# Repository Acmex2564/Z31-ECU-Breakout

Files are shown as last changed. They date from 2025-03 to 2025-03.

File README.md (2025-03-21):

#Z31-ECU-Breakout

This repository contains KiCad files for a breakout board usable for the 1980s Nissan ECCS with the 36(20+16)+15 pin harness.

I used this to run an M30 ECU without chopping up my existing harness prior to fabricating a new 76-pin harness.

You will need a the 36-pin Dual-Line Interlock (DLI) header (AMP P/N 172023-1) and yet unidentified 15-pin header (looks kinda like a JPT/MCP part, marked for Mitsubishi Electric (SJB) but not in any English catalogs), and fasteners for both. The 15-pin header will need to be desoldered from a scrapped ECU; the 36-pin is available from Digikey/Mouser/etc. as of 2025.

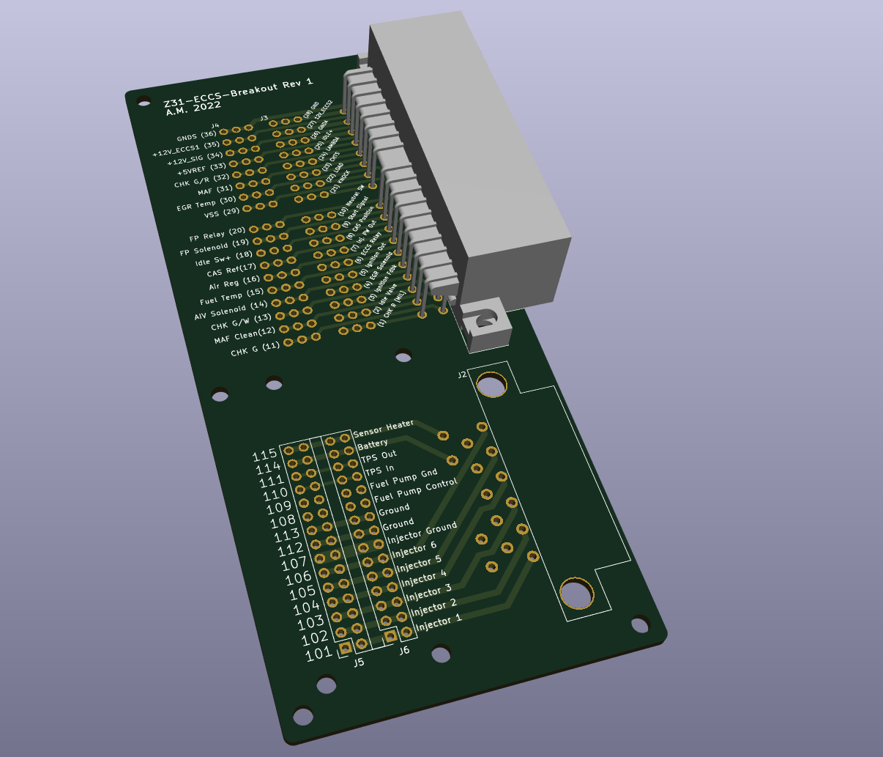
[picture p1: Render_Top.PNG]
KiCad Render of top of board


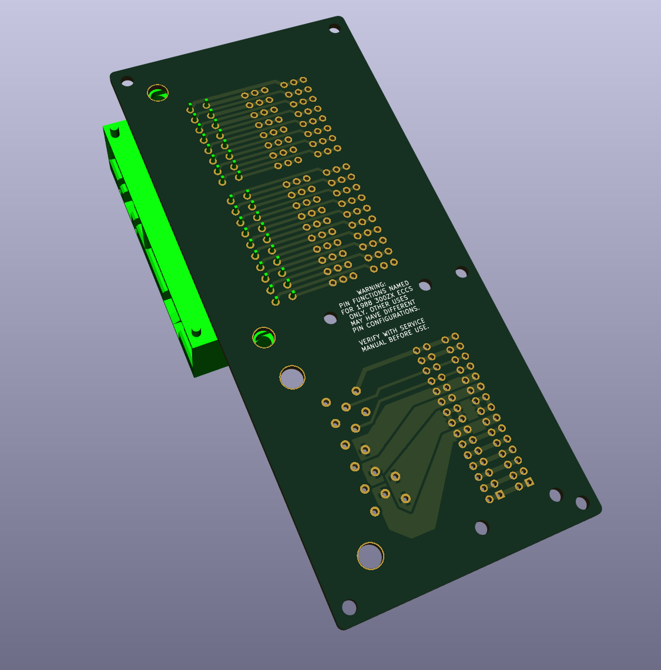
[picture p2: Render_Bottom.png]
Kicad Render of bottom of board


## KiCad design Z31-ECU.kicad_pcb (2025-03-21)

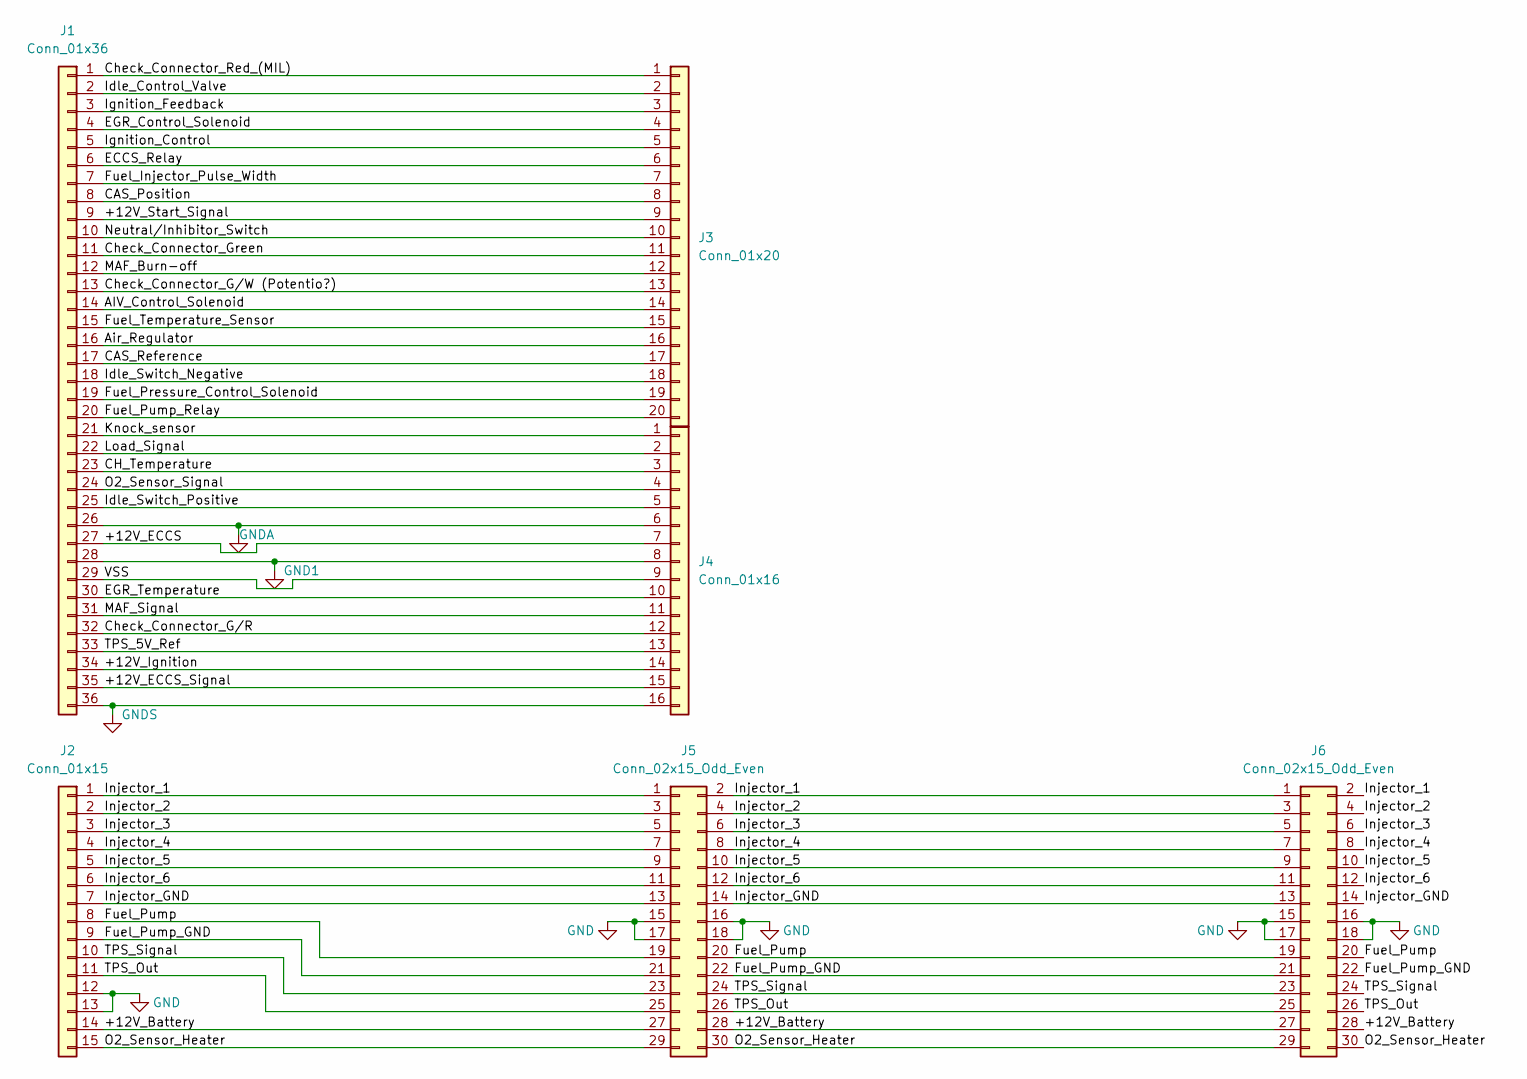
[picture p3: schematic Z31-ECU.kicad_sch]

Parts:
J1: Conn_01x36; TE-172023_Reverse_Number
J2: Conn_01x15; Z31_15p_ECU
J3: Conn_01x20; Z31_ECU_Breakout_2
J4: Conn_01x16; Z31_ECU_Breakout_1
J5, J6: Conn_02x15_Odd_Even; PinSocket_2x15_P2.54mm_Vertical

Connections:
/+12V_Battery: J2.14, J5.27, J5.28, J6.27, J6.28
/+12V_ECCS: J1.27, J4.7
/+12V_ECCS_Signal: J1.35, J4.15
/+12V_Ignition: J1.34, J4.14
/+12V_Start_Signal: J1.9, J3.9
/AIV_Control_Solenoid: J1.14, J3.14
/Air_Regulator: J1.16, J3.16
/CAS_Position: J1.8, J3.8
/CAS_Reference: J1.17, J3.17
/CH_Temperature: J1.23, J4.3
/Check_Connector_Green: J1.11, J3.11
/Check_Connector_G/R: J1.32, J4.12
/Check_Connector_G/W (Potentio?): J1.13, J3.13
/Check_Connector_Red_(MIL): J1.1, J3.1
/ECCS_Relay: J1.6, J3.6
/EGR_Control_Solenoid: J1.4, J3.4
/EGR_Temperature: J1.30, J4.10
/Fuel_Injector_Pulse_Width: J1.7, J3.7
/Fuel_Pressure_Control_Solenoid: J1.19, J3.19
/Fuel_Pump: J2.8, J5.19, J5.20, J6.19, J6.20
/Fuel_Pump_GND: J2.9, J5.21, J5.22, J6.21, J6.22
/Fuel_Pump_Relay: J1.20, J3.20
/Fuel_Temperature_Sensor: J1.15, J3.15
/Idle_Control_Valve: J1.2, J3.2
/Idle_Switch_Negative: J1.18, J3.18
/Idle_Switch_Positive: J1.25, J4.5
/Ignition_Control: J1.5, J3.5
/Ignition_Feedback: J1.3, J3.3
/Injector_1: J2.1, J5.1, J5.2, J6.1, J6.2
/Injector_2: J2.2, J5.3, J5.4, J6.3, J6.4
/Injector_3: J2.3, J5.5, J5.6, J6.5, J6.6
/Injector_4: J2.4, J5.7, J5.8, J6.7, J6.8
/Injector_5: J2.5, J5.9, J5.10, J6.9, J6.10
/Injector_6: J2.6, J5.11, J5.12, J6.11, J6.12
/Injector_GND: J2.7, J5.13, J5.14, J6.13, J6.14
/Knock_sensor: J1.21, J4.1
/Load_Signal: J1.22, J4.2
/MAF_Burn-off: J1.12, J3.12
/MAF_Signal: J1.31, J4.11
/Neutral/Inhibitor_Switch: J1.10, J3.10
/O2_Sensor_Heater: J2.15, J5.29, J5.30, J6.29, J6.30
/O2_Sensor_Signal: J1.24, J4.4
/TPS_5V_Ref: J1.33, J4.13
/TPS_Out: J2.11, J5.25, J5.26, J6.25, J6.26
/TPS_Signal: J2.10, J5.23, J5.24, J6.23, J6.24
/VSS: J1.29, J4.9
GND: J2.12, J2.13, J5.15, J5.16, J5.17, J5.18, J6.15, J6.16, J6.17, J6.18
GND1: J1.28, J4.8
GNDA: J1.26, J4.6
GNDS: J1.36, J4.16

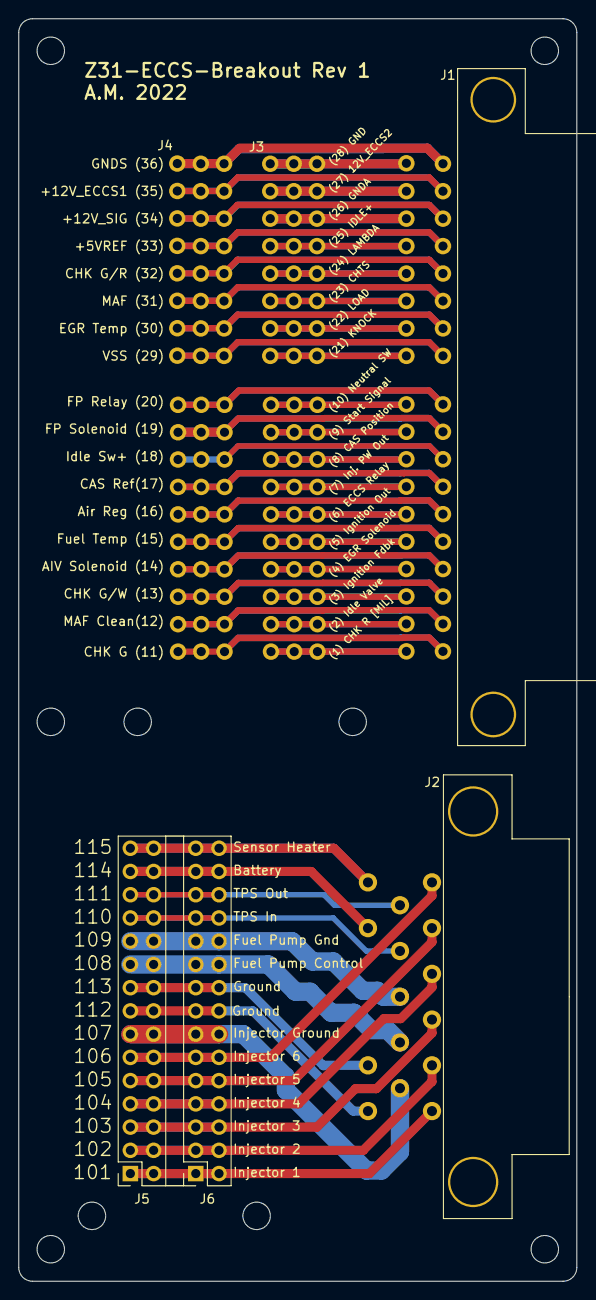
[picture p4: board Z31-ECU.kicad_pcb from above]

Board: 2 copper layers, 61.0 x 138.0 mm, 6 parts (0 on the bottom side), 50 nets.

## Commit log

2025-03-21 Add Z31 ECCS breakout board files (useful reference)
    [Z31-ECU.kicad_pcb, Z31-ECU.kicad_sch]
2025-03-21 Add readme.md and KiCad renders of board
